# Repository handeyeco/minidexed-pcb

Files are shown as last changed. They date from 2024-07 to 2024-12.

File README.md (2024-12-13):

> [!CAUTION]
> This project was made by a JavaScript developer, not an electrical engineer.
>
> It should be assumed that everything is wrong and the project will set your house on fire.
>
> I am not responsible for anything ever.

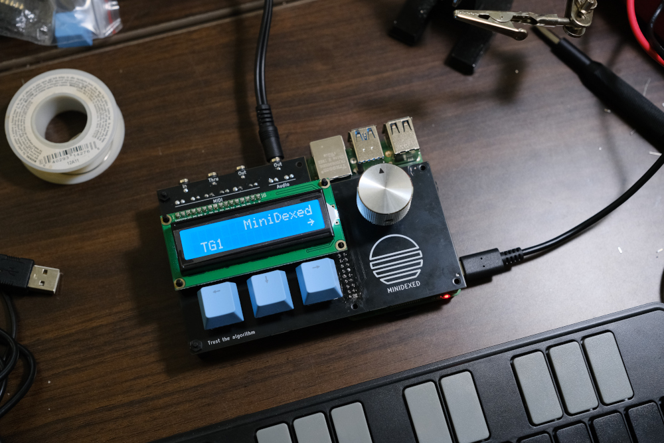
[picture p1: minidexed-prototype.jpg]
MiniDexed


# MiniDexed PCB

Custom PCB for [MiniDexed](https://github.com/probonopd/MiniDexed), an open-source FM synthesizer. It has:

- An endless encoder
- 3 Cherry buttons (back/home/select)
- A 1602 display
- 3.5mm TRS MIDI in/thru/out
- USB MIDI
- 3.5mm TRS audio out (via the PCM5102 DAC)

See the [writeup on my blog](https://handeyeco.github.io/tech-blog/minidexed-pcb/) for a full explanation of the circuit.

Thanks to lots of folks!

- [probonopd](https://github.com/probonopd) and the whole MiniDexed team
- [diyelectromusic](https://diyelectromusic.com/) for MiniDexed work and PCB design notes
- The whole [Dexed](https://github.com/asb2m10/dexed) lineage
- The [KiCad](https://www.kicad.org/) maintainers

## Builds

Look in `/gerbers/` for build files and BOMs.

### 20240727

Working with the [MiniDexed 2024-01-16 release](https://github.com/probonopd/MiniDexed/releases/tag/2024-01-16).

No known issues (although MIDI out is untested right now). The whole thing is about the size of a Korg NTS-1 and costs roughly $15/PCB to make (including SMT assembly and SMT parts; not including the Pi, THT components, or shipping).

Required changes to `minidexed.ini`:

```
# Sound device
SoundDevice=i2s
#SoundDevice=pwm
#SoundDevice=hdmi

# ...unchanged...

ButtonPinBack=16
ButtonActionBack=click
ButtonPinSelect=27
ButtonActionSelect=click
ButtonPinHome=26
ButtonActionHome=click

# ...unchanged...
```

- For JLCPCB PCB assembly
  - SMD BOM is `minidexed-bom-smd.csv`
  - Pick-and-place position file is `minidexed-bottom-pos.csv`
  - I'm not an expert and can't help much, I followed [this video](https://www.youtube.com/watch?v=VejO8rDdhzo)
- Non-SMD components:
  - x1 [RPi](https://www.adafruit.com/product/3055)
    - I used the 3 because the 4 is hot AF
  - x3 [Cherry switches](https://www.digikey.com/en/products/detail/cherry-americas-llc/MX1A-E1NW/20180) 
    - PCB-mount is best: `MX1A-_1NW`, the `W` is PCB mount
  - x3 Cherry compatible key caps
  - x1 Encoder
    - I have no idea what encoder I used, [maybe this](https://www.digikey.com/en/products/detail/bourns-inc/PEC11R-4215F-S0012/4499664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)
    - I used a switched encoder
    - Shaft height/style depends on the enclosure/knob
  - x1 Knob for the encoder
  - x4 3.5mm TRS
    - [Like this one](https://www.mouser.com/ProductDetail/SparkFun/PRT-08032?qs=WyAARYrbSnZFBWwuc8Qktw%3D%3D)
    - I like the switched ones because they have 5 pins vs 3 pins which makes the connection to the PCB more solid
    - MIDI is TRS, that's why there's 4 (x3 MIDI, x1 audio)
  - x1 16x2 LCD display
    - My understanding is that these 16x2 LCDs are pretty generic, something [like this](https://www.adafruit.com/product/181) should work
  - x1 10k (103) trim pot
    - For the LCD; [like these](https://www.amazon.com/gp/product/B0CZVY726N)
  - x1 2x20 2.54mm female header (for the Pi)
  - x1 1x16 2.54mm male header (for the LCD)
  - x1 1x16 2.54mm female header (for the LCD)
    - optional, I soldered mine into the PCB to keep things short
  - I think all the mounting holes and spacers are M2.5 (since that's what the Pi uses)
  - All this stuff is pretty generic and highly available
  - **Don't trust me**, double check your footprints or be prepared to reorder things

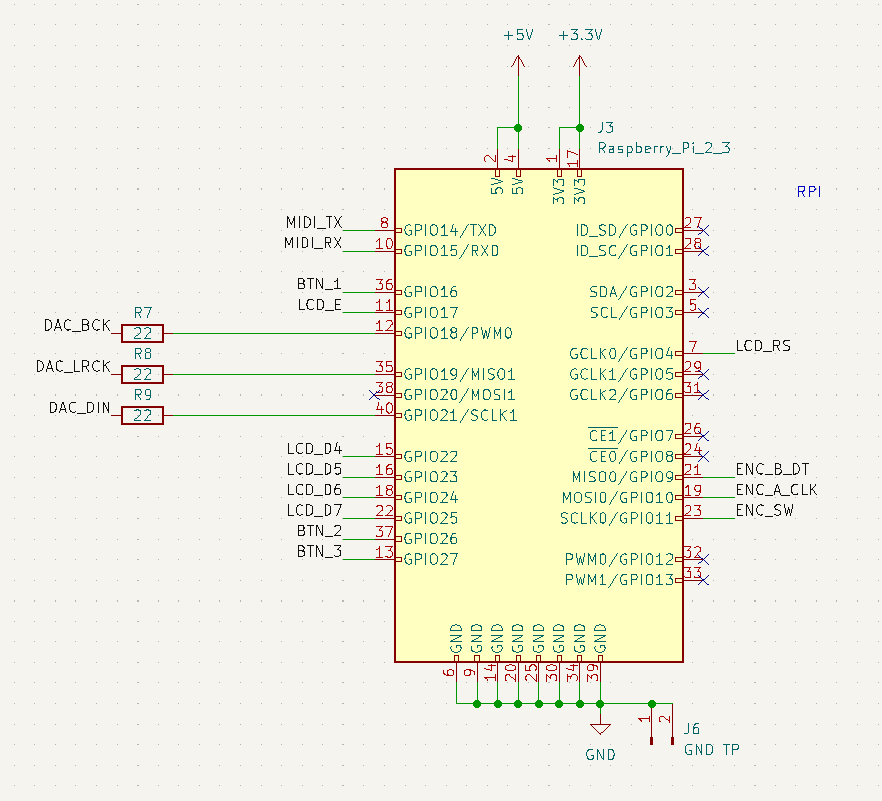
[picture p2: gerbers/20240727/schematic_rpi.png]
RPi schematic

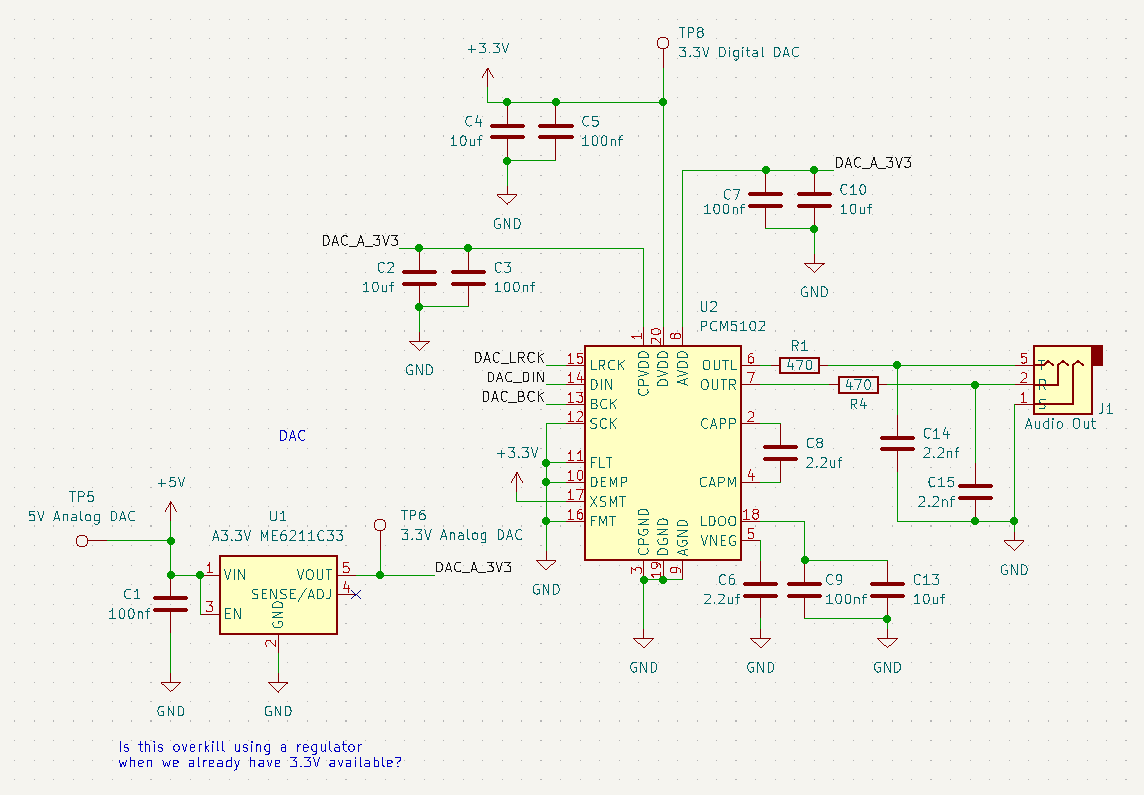
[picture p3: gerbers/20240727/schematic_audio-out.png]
Audio schematic

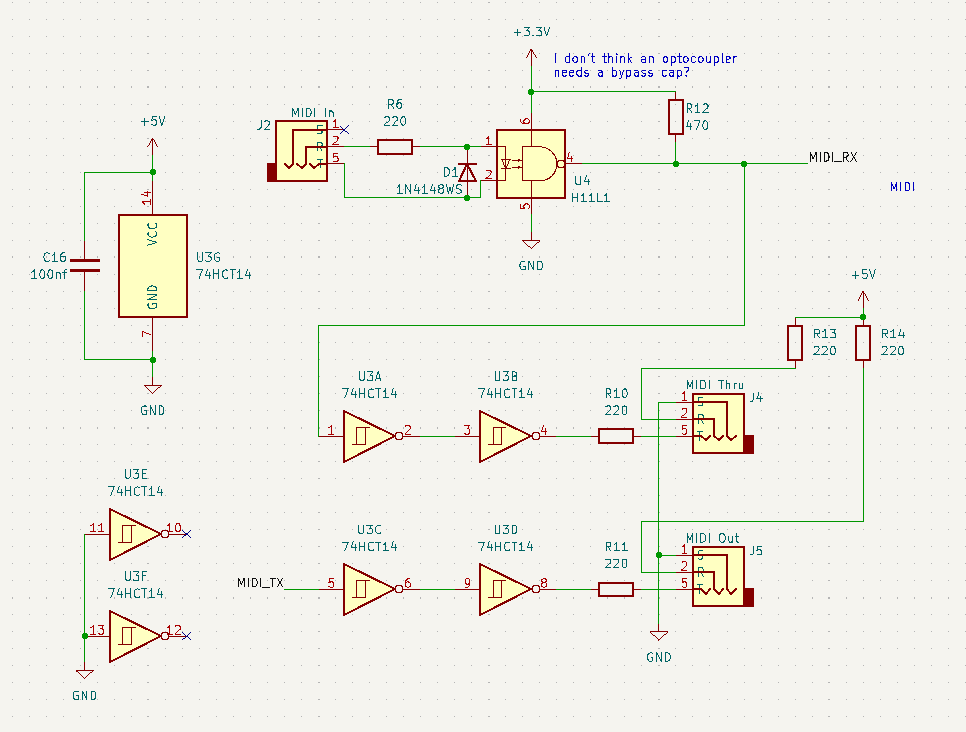
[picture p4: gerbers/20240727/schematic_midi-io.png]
MIDI schematic

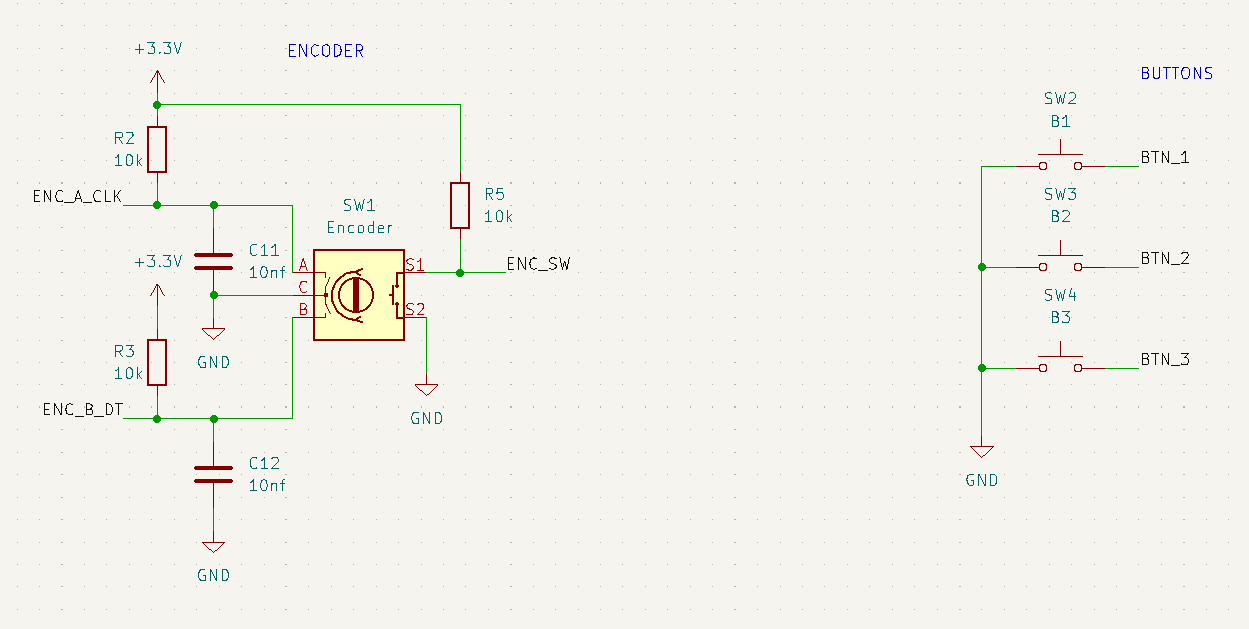
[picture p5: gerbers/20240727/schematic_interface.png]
Interface schematic

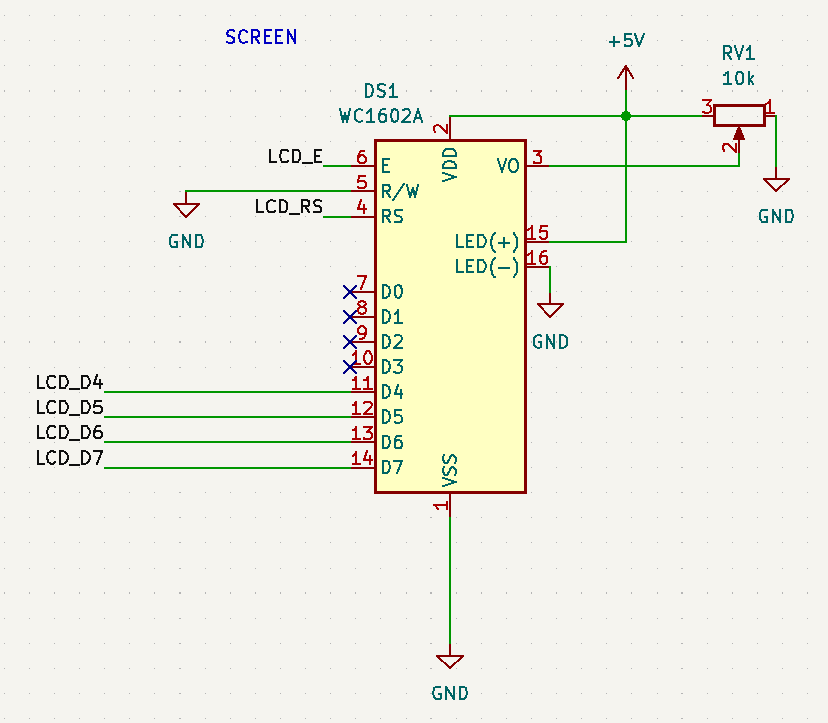
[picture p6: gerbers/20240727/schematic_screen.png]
Screen schematic


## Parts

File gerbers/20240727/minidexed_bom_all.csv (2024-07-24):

Comment | Designator | Footprint | LCSC
100nf | C1,C3,C5,C7,C9,C16 | Capacitor_SMD:C_0805_2012Metric_Pad1.18x1.45mm_HandSolder | C472810
10nf | C11,C12 | Capacitor_SMD:C_0805_2012Metric_Pad1.18x1.45mm_HandSolder | C77455
2.2nf | C14,C15 | Capacitor_SMD:C_0805_2012Metric_Pad1.18x1.45mm_HandSolder | C395967
10uf | C2,C4,C10,C13 | Capacitor_SMD:C_0805_2012Metric_Pad1.18x1.45mm_HandSolder | C111662
2.2uf | C6,C8 | Capacitor_SMD:C_0805_2012Metric_Pad1.18x1.45mm_HandSolder | C6119894
1N4148WS | D1 | Diode_SMD:D_SOD-323 | C2128
WC1602A | DS1 | Display:WC1602A
MountingHole | H1,H2,H3 | MountingHole:MountingHole_2.7mm_M2.5
Audio Out | J1 | sparkfun 3.5mm:sparkfun_3.5mm_trs
MIDI In | J2 | sparkfun 3.5mm:sparkfun_3.5mm_trs
Raspberry_Pi_2_3 | J3 | raspberry-pi_rpi_hat:raspberry-pi_rpi_hat
MIDI Thru | J4 | sparkfun 3.5mm:sparkfun_3.5mm_trs
MIDI Out | J5 | sparkfun 3.5mm:sparkfun_3.5mm_trs
GND TP | J6 | Connector_PinHeader_2.54mm:PinHeader_1x02_P2.54mm_Vertical
470 | R1,R4,R12 | Resistor_SMD:R_1206_3216Metric_Pad1.30x1.75mm_HandSolder | C104814
10k | R2,R3,R5 | Resistor_SMD:R_1206_3216Metric_Pad1.30x1.75mm_HandSolder | C2073539
220 | R6,R10,R11,R13,R14 | Resistor_SMD:R_1206_3216Metric_Pad1.30x1.75mm_HandSolder | C872616
22 | R7,R8,R9 | Resistor_SMD:R_1206_3216Metric_Pad1.30x1.75mm_HandSolder | C912903
10k | RV1 | Potentiometer_THT:Potentiometer_Runtron_RM-065_Vertical
Encoder | SW1 | Rotary_Encoder:RotaryEncoder_Alps_EC11E-Switch_Vertical_H20mm
B1 | SW2 | Button_Switch_Keyboard:SW_Cherry_MX_1.00u_PCB
B2 | SW3 | Button_Switch_Keyboard:SW_Cherry_MX_1.00u_PCB
B3 | SW4 | Button_Switch_Keyboard:SW_Cherry_MX_1.00u_PCB
5V Analog DAC | TP5 | TestPoint:TestPoint_Pad_D1.0mm
3.3V Analog DAC | TP6 | TestPoint:TestPoint_Pad_D1.0mm
3.3V Digital DAC | TP8 | TestPoint:TestPoint_Pad_D1.0mm
A3.3V ME6211C33 | U1 | Package_TO_SOT_SMD:TSOT-23-5 | C82942
PCM5102 | U2 | Package_SO:TSSOP-20_4.4x6.5mm_P0.65mm | C107671
74HCT14 | U3 | Package_SO:TSSOP-14_4.4x5mm_P0.65mm | C133639
H11L1 | U4 | SOP-6_6.5x7.12mm_P2.54mm:SOP-6_6.5x7.12mm_P2.54mm | C78589

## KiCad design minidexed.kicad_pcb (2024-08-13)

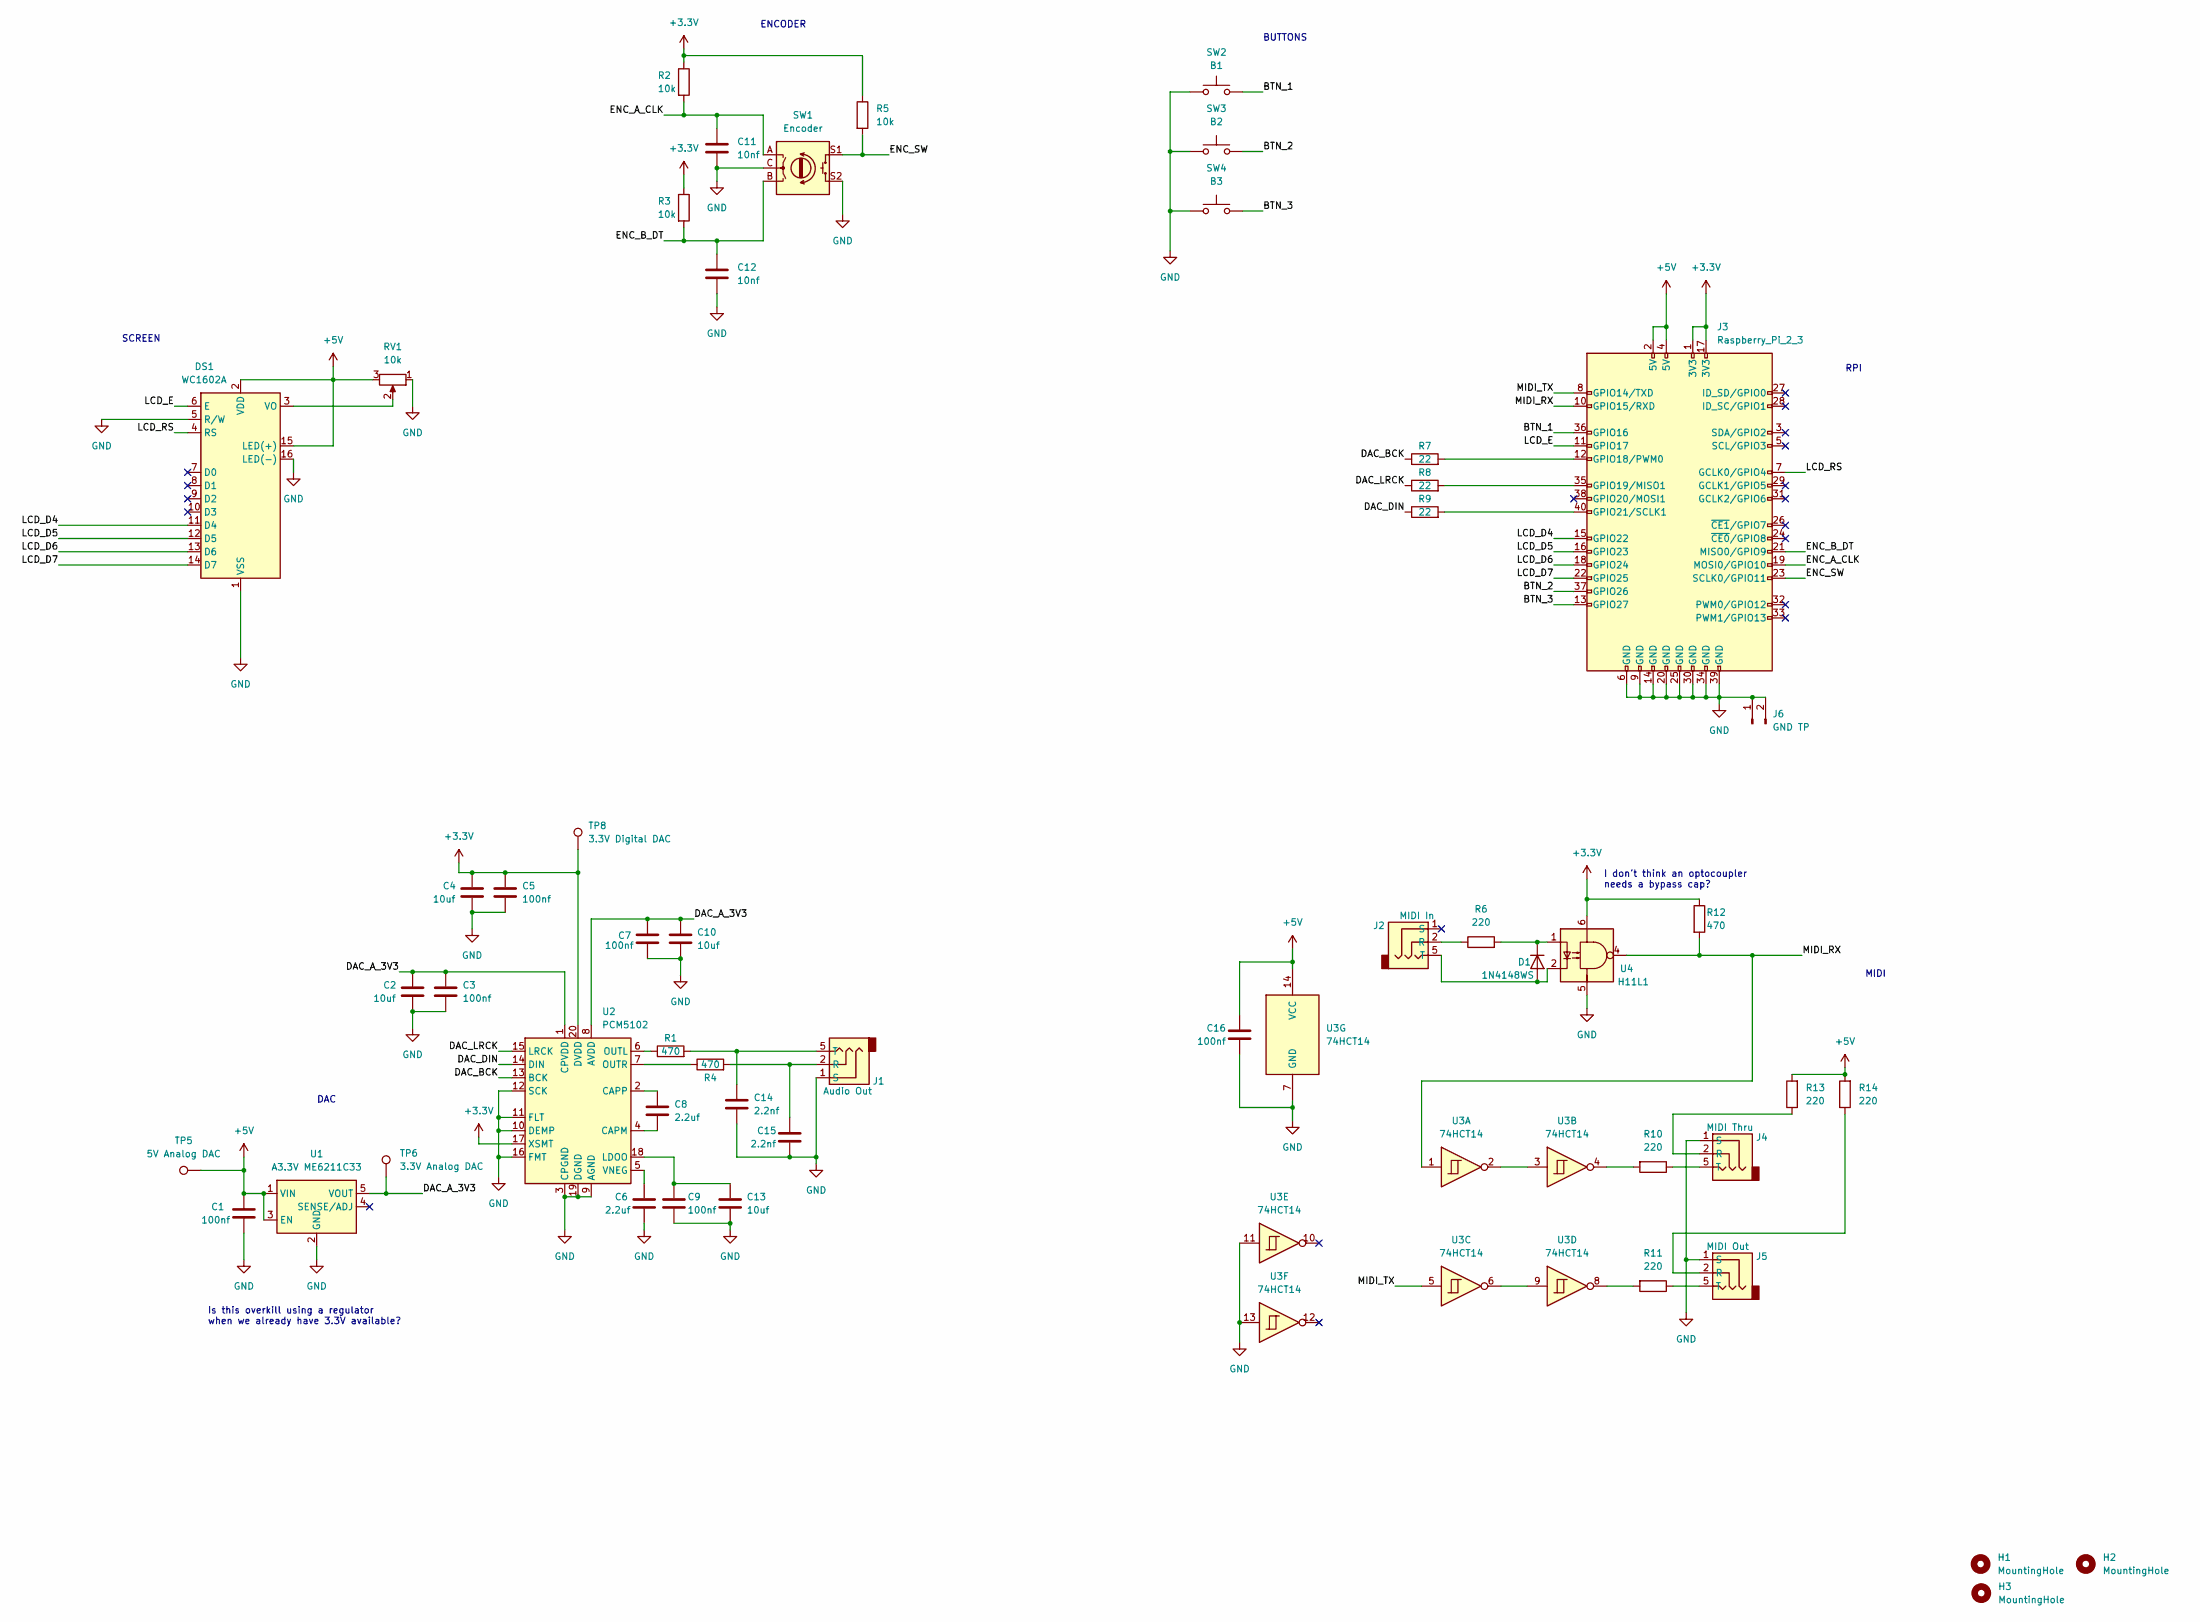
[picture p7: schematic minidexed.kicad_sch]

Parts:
C1, C3, C5, C7, C9, C16: 100nf; C_0805_2012Metric_Pad1.18x1.45mm_HandSolder; LCSC C472810
C2, C4, C10, C13: 10uf; C_0805_2012Metric_Pad1.18x1.45mm_HandSolder; LCSC C111662
C6, C8: 2.2uf; C_0805_2012Metric_Pad1.18x1.45mm_HandSolder; LCSC C6119894
C11, C12: 10nf; C_0805_2012Metric_Pad1.18x1.45mm_HandSolder; LCSC C77455
C14, C15: 2.2nf; C_0805_2012Metric_Pad1.18x1.45mm_HandSolder; LCSC C395967
D1: 1N4148WS; D_SOD-323; LCSC C2128
DS1: WC1602A
H1, H2, H3: MountingHole; MountingHole_2.7mm_M2.5
J1: Audio Out; sparkfun_3.5mm_trs
J2: MIDI In; sparkfun_3.5mm_trs
J3: Raspberry_Pi_2_3; raspberry-pi_rpi_hat
J4: MIDI Thru; sparkfun_3.5mm_trs
J5: MIDI Out; sparkfun_3.5mm_trs
J6: GND TP; PinHeader_1x02_P2.54mm_Vertical
R1, R4, R12: 470; R_1206_3216Metric_Pad1.30x1.75mm_HandSolder; LCSC C104814
R2, R3, R5: 10k; R_1206_3216Metric_Pad1.30x1.75mm_HandSolder; LCSC C2073539
R6, R10, R11, R13, R14: 220; R_1206_3216Metric_Pad1.30x1.75mm_HandSolder; LCSC C872616
R7, R8, R9: 22; R_1206_3216Metric_Pad1.30x1.75mm_HandSolder; LCSC C912903
RV1: 10k; Potentiometer_Runtron_RM-065_Vertical
SW1: Encoder; RotaryEncoder_Alps_EC11E-Switch_Vertical_H20mm
SW2: B1; SW_Cherry_MX_1.00u_PCB
SW3: B2; SW_Cherry_MX_1.00u_PCB
SW4: B3; SW_Cherry_MX_1.00u_PCB
TP5: 5V Analog DAC; TestPoint_Pad_D1.0mm
TP6: 3.3V Analog DAC; TestPoint_Pad_D1.0mm
TP8: 3.3V Digital DAC; TestPoint_Pad_D1.0mm
U1: A3.3V ME6211C33; TSOT-23-5; LCSC C82942
U2: PCM5102; TSSOP-20_4.4x6.5mm_P0.65mm; LCSC C107671
U3: 74HCT14; TSSOP-14_4.4x5mm_P0.65mm; LCSC C133639
U4: H11L1; SOP-6_6.5x7.12mm_P2.54mm; LCSC C78589

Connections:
+3.3V: C4.1, C5.1, J3.1 (3V3), J3.17 (3V3), R2.1, R3.1, R5.1, R12.1, TP8.1, U2.17 (XSMT), U2.20 (DVDD), U4.6
+5V: C1.1, C16.1, DS1.2 (VDD), DS1.15 (LED(+)), J3.2 (5V), J3.4 (5V), R13.2, R14.2, RV1.3, TP5.1, U1.1 (VIN), U1.3 (EN), U3.14 (VCC)
/BTN_1: J3.36 (GPIO16), SW2.2
/BTN_2: J3.37 (GPIO26), SW3.2
/BTN_3: J3.13 (GPIO27), SW4.2
/DAC_A_3V3: C2.1, C3.1, C7.1, C10.1, TP6.1, U1.5 (VOUT), U2.1 (CPVDD), U2.8 (AVDD)
/DAC_BCK: R7.1, U2.13 (BCK)
/DAC_DIN: R9.1, U2.14 (DIN)
/DAC_LRCK: R8.1, U2.15 (LRCK)
/ENC_A_CLK: C11.1, J3.19 (MOSI0/GPIO10), R2.2, SW1.A
/ENC_B_DT: C12.1, J3.21 (MISO0/GPIO9), R3.2, SW1.B
/ENC_SW: J3.23 (SCLK0/GPIO11), R5.2, SW1.S1
/LCD_D4: DS1.11 (D4), J3.15 (GPIO22)
/LCD_D5: DS1.12 (D5), J3.16 (GPIO23)
/LCD_D6: DS1.13 (D6), J3.18 (GPIO24)
/LCD_D7: DS1.14 (D7), J3.22 (GPIO25)
/LCD_E: DS1.6 (E), J3.11 (GPIO17)
/LCD_RS: DS1.4 (RS), J3.7 (GCLK0/GPIO4)
/MIDI_RX: J3.10 (GPIO15/RXD), R12.2, U3.1, U4.4
/MIDI_TX: J3.8 (GPIO14/TXD), U3.5
GND: C1.2, C2.2, C3.2, C4.2, C5.2, C6.2, C7.2, C9.2, C10.2, C11.2, C12.2, C13.2, C14.2, C15.2, C16.2, DS1.1 (VSS), DS1.5 (R/W), DS1.16 (LED(-)), J1.1 (S), J3.6 (GND), J3.9 (GND), J3.14 (GND), J3.20 (GND), J3.25 (GND), J3.30 (GND), J3.34 (GND), J3.39 (GND), J4.1 (S), J5.1 (S), J6.1, J6.2, RV1.1, SW1.C, SW1.S2, SW2.1, SW3.1, SW4.1, U1.2 (GND), U2.3 (CPGND), U2.9 (AGND), U2.10 (DEMP), U2.11 (FLT), U2.12 (SCK), U2.16 (FMT), U2.19 (DGND), U3.7 (GND), U3.11, U3.13, U4.5
unnamed: C6.1, U2.5 (VNEG)
unnamed: C8.1, U2.2 (CAPP)
unnamed: C8.2, U2.4 (CAPM)
unnamed: C9.1, C13.1, U2.18 (LDOO)
unnamed: C14.1, J1.5 (T), R1.2
unnamed: C15.1, J1.2 (R), R4.2
unnamed: D1.1 (K), R6.2, U4.1
unnamed: D1.2 (A), J2.5 (T), U4.2
unnamed: DS1.3 (VO), RV1.2
unnamed: J2.2 (R), R6.1
unnamed: J3.12 (GPIO18/PWM0), R7.2
unnamed: J3.35 (GPIO19/MISO1), R8.2
unnamed: J3.40 (GPIO21/SCLK1), R9.2
unnamed: J4.2 (R), R13.1
unnamed: J4.5 (T), R10.1
unnamed: J5.2 (R), R14.1
unnamed: J5.5 (T), R11.1
unnamed: R1.1, U2.6 (OUTL)
unnamed: R4.1, U2.7 (OUTR)
unnamed: R10.2, U3.4
unnamed: R11.2, U3.8
unnamed: U3.2, U3.3
unnamed: U3.6, U3.9

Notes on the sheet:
Is this overkill using a regulator when we already have 3.3V available?
I don't think an optocoupler needs a bypass cap?
ENCODER
SCREEN
MIDI
BUTTONS
DAC
RPI

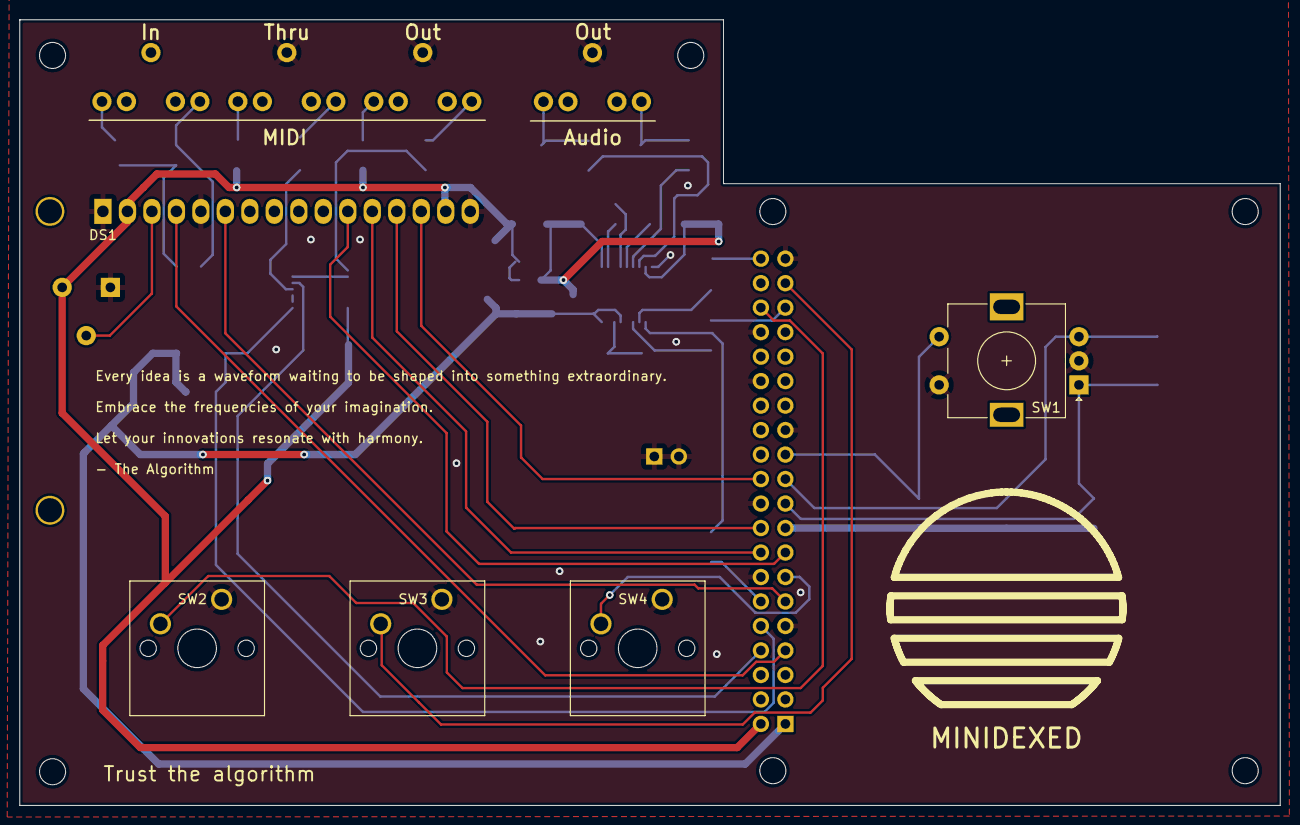
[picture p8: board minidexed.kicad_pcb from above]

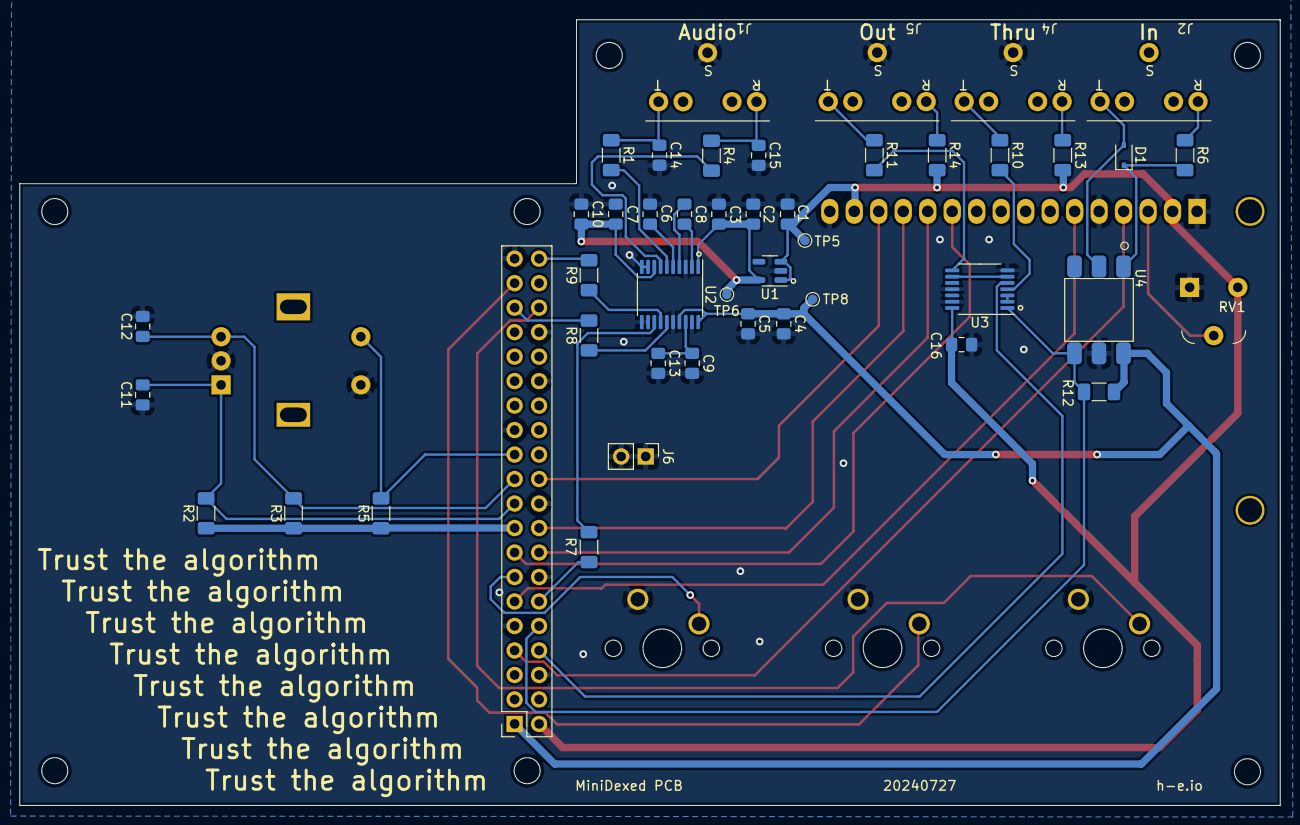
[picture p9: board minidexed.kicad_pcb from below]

Board: 2 copper layers, 130.8 x 81.5 mm, 53 parts (44 on the bottom side), 44 nets.

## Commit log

2024-07-15 6N138 version
    [dac.kicad_sch, interface.kicad_sch, midi-io.kicad_sch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]
2024-07-21 rough out tracks
    [minidexed.kicad_pcb, minidexed.kicad_sch]
2024-07-21 add image errors
    [minidexed.kicad_pcb]
2024-07-22 fix gnd issue
    [minidexed.kicad_pcb]
2024-07-22 fix missing GND connection
    [minidexed.kicad_pcb]
2024-07-22 rewire LED
    [minidexed.kicad_pcb]
2024-07-23 update opto footprint
    [minidexed.kicad_pcb, minidexed.kicad_sch, minidexed_bom_all.csv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]
2024-07-24 export files
    [minidexed-B_Cu.gbl, minidexed-B_Mask.gbs, minidexed-B_Paste.gbp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]
2024-08-13 organize build files
    [minidexed-B_Cu.gbl, minidexed-B_Mask.gbs, minidexed-B_Paste.gbp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]
2024-09-29 add acrylic faceplates
    [minidexed.kicad_sch]
